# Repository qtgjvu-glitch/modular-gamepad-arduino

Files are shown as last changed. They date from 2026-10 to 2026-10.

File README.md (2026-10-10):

# 🎮 雙手體感手把與模組化轉接系統 (Modular Controller System)

本專案為雙手遊戲控制器之硬體原型（Prototype）與驗證韌體。系統包含左手手把、右手手把，以及中央 I2C 訊號轉接板，具備完全模組化與物理防呆設計。

---

## 📌 系統架構與 I2C 設備配置

- **左手控制器**：
  - MPU-6050 姿態感測器 (I2C 位址: `0x68`)
  - PS2 雙軸搖桿 (X/Y 軸類比輸入 + SW 按鈕)
  - 專用 **5-Pin 模組化介面**
- **右手控制器**：
  - MPU-6050 姿態感測器 (I2C 位址: `0x69`，AD0 腳位拉高)
  - 4 鍵獨立微動按鈕 (ABXY，使用 Arduino 內建上拉電阻)
  - 專用 **6-Pin 模組化介面**
- **中央轉接模組 (Central Adapter Board)**：
  - 基於 Arduino UNO 進行電源分配與 I2C 總線匯流
  - 整合集線束帶與防拉扯機構 (Strain Relief)

---

## ⚡ 標準電源與操作規範 (防燒毀 SOP)

為保護敏感之 MPU-6050 MEMS 感測晶片，請嚴格遵守以下操作順序：

1. **嚴禁熱插拔**：拆裝任何模組排線前，務必先拔除 Arduino 的 USB/電源。
2. **通電順序**：接妥左右手排線與轉接板 $\rightarrow$ 插上 USB 供電。
3. **斷電順序**：拔除 USB 供電 $\rightarrow$ 拆卸排線。

---

## 🛡️ 物理防呆設計 (Poka-Yoke)

- 左手與右手排線介面採用 **5-Pin vs 6-Pin 不對稱插頭結構**。
- 物理尺寸差異可完全杜絕左右手插頭誤插或反插導致之電源短路風險。

---

## 📁 檔案結構

- `/firmware`：Arduino UNO 驗證程式 (`sketch_oct5a.ino`)
- `/docs`：機構尺寸測量數據與腳位對照表
- `/3d_models`：3D 列印外殼 CAD 檔案 (STL / STEP)

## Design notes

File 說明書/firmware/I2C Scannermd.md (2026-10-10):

#include <Wire.h>

void setup() {
  Wire.begin();
  Serial.begin(9600);
  while (!Serial);
  Serial.println("\nI2C 設備掃描測試中...");
}

void loop() {
  byte error, address;
  int nDevices = 0;

  for(address = 1; address < 127; address++ ) {
    Wire.beginTransmission(address);
    error = Wire.endTransmission();

    if (error == 0) {
      Serial.print("找到 I2C 設備！位址：0x");
      if (address<16) Serial.print("0");
      Serial.print(address, HEX);
      Serial.println();
      nDevices++;
    }
  }
  if (nDevices == 0)
    Serial.println("未找到任何 I2C 設備，請檢查焊接或接線！\n");
  
  delay(2000);
}

硬體接線：
VCC (紅) $\rightarrow$ Arduino 5V（或 3.3V）   
GND (黑) $\rightarrow$ Arduino GND   
SCL (白) $\rightarrow$ Arduino A5   
SDA (紫) $\rightarrow$ Arduino A4   
AD0 (黃) $\rightarrow$ 先接 Arduino GND

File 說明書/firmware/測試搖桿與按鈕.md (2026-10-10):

void setup() {
  Serial.begin(9600);
  // 設定 D2 為按鈕輸入，並開啟內建上拉電阻
  pinMode(2, INPUT_PULLUP);
}

void loop() {
  int xValue = analogRead(A0);  // 讀取 X 軸 (0 ~ 1023)
  int yValue = analogRead(A1);  // 讀取 Y 軸 (0 ~ 1023)
  int swState = digitalRead(2); // 讀取按鈕 (1 為放開，0 為按下)

  Serial.print("X軸: ");
  Serial.print(xValue);
  Serial.print(" | Y軸: ");
  Serial.print(yValue);
  Serial.print(" | 按鈕: ");
  if (swState == LOW) {
    Serial.println("【按下！】");
  } else {
    Serial.println("放開");
  }

  delay(200); // 每 0.2 秒更新一次
}

PS2 搖桿 5 針腳對應表
搖桿模組標籤     作用說明                    接到 Arduino UNO 的位置
GND            負極（接地）                接洞洞板 GND 總線（或 Arduino GND）
+5V (或 VCC)   正極（電源）                 接洞洞板 5V 總線（或 Arduino 5V）
VRX            X軸左右搖動（類比訊號）       接 Arduino 的 A0 腳位   
VRY            Y 軸上下搖動（類比訊號）      接 Arduino 的 A1 腳位   
SW             搖桿向下按壓開關（數位訊號）   接 Arduino 的 D2 腳位

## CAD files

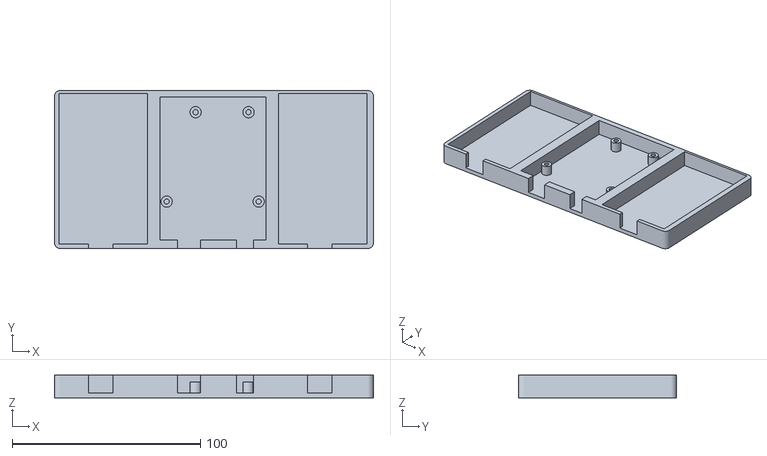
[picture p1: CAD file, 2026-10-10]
說明書/3d_models/modular_docking_base.stl
169.5 x 84.0 x 12.0

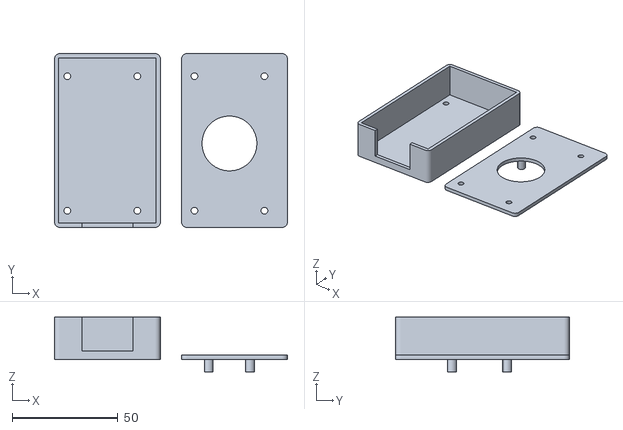
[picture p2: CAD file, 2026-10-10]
說明書/3d_models/left_hand_controller6.stl
110.2 x 82.2 x 26.0

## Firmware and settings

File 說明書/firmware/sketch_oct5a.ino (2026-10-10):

#include <Wire.h>

// MPU-6050 I2C 位址
const int MPU_LEFT  = 0x68; // 左手板
const int MPU_RIGHT = 0x69; // 右手板

// 儲存姿態角度 (簡易計算)
int16_t AcX1, AcY1, AcZ1;
int16_t AcX2, AcY2, AcZ2;

void setup() {
  Serial.begin(9600);
  Wire.begin();

  // 初始化左手 MPU6050
  Wire.beginTransmission(MPU_LEFT);
  Wire.write(0x6B); // PWR_MGMT_1 register
  Wire.write(0);    // 喚醒 MPU6050
  Wire.endTransmission(true);

  // 初始化右手 MPU6050
  Wire.beginTransmission(MPU_RIGHT);
  Wire.write(0x6B);
  Wire.write(0);
  Wire.endTransmission(true);

  // 初始化按鈕腳位
  pinMode(2, INPUT_PULLUP); // 搖桿 SW 按鈕
  pinMode(3, INPUT_PULLUP); // 按鈕 A
  pinMode(4, INPUT_PULLUP); // 按鈕 B
  pinMode(5, INPUT_PULLUP); // 按鈕 X
  pinMode(6, INPUT_PULLUP); // 按鈕 Y
}

void loop() {
  // 1. 讀取左手 MPU6050 (0x68)
  Wire.beginTransmission(MPU_LEFT);
  Wire.write(0x3B); // 從 ACCEL_XOUT_H 開始讀取
  Wire.endTransmission(false);
  Wire.requestFrom(MPU_LEFT, 6, true);
  AcX1 = Wire.read() << 8 | Wire.read();
  AcY1 = Wire.read() << 8 | Wire.read();
  AcZ1 = Wire.read() << 8 | Wire.read();

  // 2. 讀取右手 MPU6050 (0x69)
  Wire.beginTransmission(MPU_RIGHT);
  Wire.write(0x3B);
  Wire.endTransmission(false);
  Wire.requestFrom(MPU_RIGHT, 6, true);
  AcX2 = Wire.read() << 8 | Wire.read();
  AcY2 = Wire.read() << 8 | Wire.read();
  AcZ2 = Wire.read() << 8 | Wire.read();

  // 3. 讀取搖桿與按鈕
  int joyX = analogRead(A0);
  int joyY = analogRead(A1);
  int joySW = (digitalRead(2) == LOW) ? 1 : 0;
  int btnA  = (digitalRead(3) == LOW) ? 1 : 0;
  int btnB  = (digitalRead(4) == LOW) ? 1 : 0;
  int btnX  = (digitalRead(5) == LOW) ? 1 : 0;
  int btnY  = (digitalRead(6) == LOW) ? 1 : 0;

  // 4. 輸出統一通訊封包格式到 Serial Monitor
  // 格式：L_X,L_Y,L_Z | R_X,R_Y,R_Z | JoyX,JoyY,JoySW | A,B,X,Y
  Serial.print("L:");
  Serial.print(AcX1); Serial.print(","); Serial.print(AcY1); Serial.print(","); Serial.print(AcZ1);
  Serial.print(" | R:");
  Serial.print(AcX2); Serial.print(","); Serial.print(AcY2); Serial.print(","); Serial.print(AcZ2);
  Serial.print(" | JOY:");
  Serial.print(joyX); Serial.print(","); Serial.print(joyY); Serial.print(","); Serial.print(joySW);
  Serial.print(" | BTN:");
  Serial.print(btnA); Serial.print(btnB); Serial.print(btnX); Serial.println(btnY);

  delay(50); // 20Hz 刷新率
}
